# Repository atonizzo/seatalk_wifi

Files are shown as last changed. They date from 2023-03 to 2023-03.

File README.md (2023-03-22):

# <p align=center>SEATALK_WIFI</p>




---
### Table of contents
1. [Introduction](#introduction)
2. [Hardware](#hardware)
    1. [Schematic](#schematic)
        1. [Serial Bridge](#serial_bridge)
    2. [PCB Layout](#pcb_layout)
        1. [Front Side](#front_side)
        2. [Back Side](#back_side)
3. [Software](#software)
    1. [Configuration via Web Page](#web_page)
        1. [Programming Over the Air](#ota_programming)
        2. [Configuration for Wind Instrument](#wind_instrument)
    2. [Serial Logger](#serial_logger)
    3. [Telnet Logger](#telnet_logger)
    4. [NMEA Server](#nmea_server)
        1. [NMEA Talker](#nmea_talker)
    5. [Software Debug Port](#debug_port)
    6. [Integration with SignalK](#signalk)
    7. [Wind Gauges](#wind_gauges)
4. [Further Development](#further_development)
5. [Holder for ST40 devices](#st40_holder)
5. [Contact](#contact)
---

#  Introduction
The hardware and the included software of this project create a
bridge between a Raymarine SeaTalk1 instrument and NMEA. The NMEA
sentences generated are sent via a WiFi connection to a remote
client. This connection can be directly used with chart plotters such as
[OpenCPN](https://opencpn.org/).

The advantages of this solution are:

- Allows older instrumentation using SeaTalk1 to be connected to newer
chartplotters receiving NMEA sentences via WiFI
- The WiFi link allows the instrumentation to be installed in
out-of-the-way location thus freeing space in the navigation area
- The board can be installed very close to the data source and does not
require laying out data cables to a chart plotter. All that is needed
is a 12 Volt connection to the battery

#  Hardware
The hardware is a simple board with pads designed to connect to to a 12V
source on one side (typically a switched and fused boat battery) and to
a Seatalk connector on the other (see [PCB layout pictures](#pcb_layout))
board supplies 12V to power the target instrument so that the only
connection needed for the system to work is a single 12V feed from the boat
electrical panel.

The hardware board is not fused. It is expected that a 0.1A fast acting fuse
be provided on the 12V supply line immediately before the circuit. The 12V feed
that powers the circuit should also be fused at the distribution panel
or go through an appropriately sized resettable circuit breaker.

##  Schematic
Seatalk_wifi Schematic

During the development of the circuit it was noticed that the Raymarine
instrument being used (an ST40 wind instrument) was very sensitive about
loading of the SeaTalk serial line. To isolate the SeaTalk data line from
the rest of the circuitry Q2 acts as a buffer.

Q2 also inverts the polarity of the signal. The polarity is once again inverted
by the receiver integrated into U3, which also provides voltage translation
down to 3.3V.

U1 implements a regulator rated to least 2A. An earlier version of this board
designed with a linear regulator showed that the regulator tended to overheat,
which prompted a redesign using a switching topology.

###   Serial Bridge
R12 allows the board to be used as a receive-only serial to WIFI bridge. In
order to use this feature, the changes to the schematic are:

| Remove | Install |
| :---:  | :---: |
| Q1, Q2, R9 | R12 |

Now the center pad can be connected to the TX pin of the RS232 port of a
NMEA device and the serial stream of NMEA sentences can be sent out to
WIFI.

##  PCB Layout

The board has been designed using KiCad and the fabrication files are provided
in the ```fab``` directory.

Board dimensions are 31 mm x 22 mm.

###  Front Side
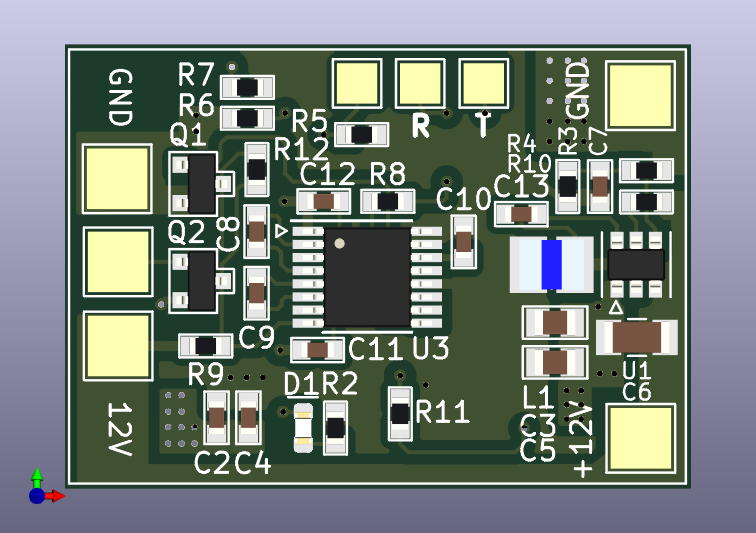
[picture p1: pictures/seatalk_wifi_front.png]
PCB Front Side


On the right side of the board the pads, from top to bottom, are:

- GND
- 12V (unfused, use a 500mA inline fuse)

These pads are connected to the boat battery. A better installation
would require powering this board from the same switched connection
that powers the navigation station.

On the left side of the board the pads are meant to be connected to a
Raymarine SeaTalk instrument. A SeaTalk1 cable has 3 wires that are
color coded and the typical color of the insulating jacket is shown
in the list. From top to bottom:

| Function | Jacket Color |
| :---: | :---: |
| GND | black or bare wire |
| SeaTalk | yellow |
| +12V |  red |

On the top side of the board the pads, from left to right, are:

- Serial Logger (unmarked on the PCB) This pin is connected to the TX pin
of serial port 2 of the ESP12 and -if enabled by the user- emits a
pretty print of all the commands handled by the hardware
(see [Serial Logger](#serial_logger))

- Programming cable RX line (marked with R in the layout). This is connected
to the RX pin of serial port 1 of the ESP12 and is primarily used to program
the device. Serial port 1 of the ESP12 device is used for both programming
the board as well as to receive the SeaTalk sentences from the instrument.
During development this means that this pin must be disconnected from the
programming cable before resetting the board to prevent interference between
the programmer hardware and the SeaTalk instrument. Failure to disconnect
this cable during regular use will prevent the SeaTalk sentences from
being received by the MCU

- Programming cable TX line (marked with T in the layout) is connected to the
TX pin of the ESP12 and is mainly used during programming. It can also be
used to output general purpose debug information but the terminal must be
programmed with the same serial parameters used by SeaTalk, which are
usually 4800 bauds, 8 bits, Even parity, 1 Stop bit.

Since the board power supply is 3.3V the typical programming is performed with a
USB to serial converter connected to pads R, T and GND. If no further software
development is expected the programming cable should be disconnected from the
board and the pads left unconnected.

###  Back Side
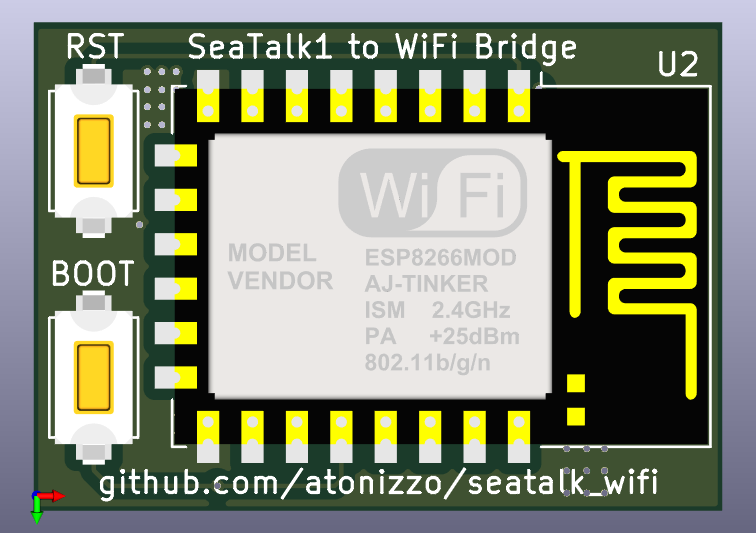
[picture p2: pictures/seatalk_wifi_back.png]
PCB Back Side


The two switches on the left side of the image are only used to program the
board when using the serial port. Once the initial firmware image is programmed
the OTA facility (see [Programming Over the Air](#ota_programming))
can then be used to reimage the flash memory thus not requiring neither the
serial port nor the toggling of the switches.

In order to program the board the RST switch (the top one in the picture)
should be pulsed **while the BOOT switch is kept pressed**. At this point
the board is ready for the programmer to write the new software.

#  Software
The software can be compiled using the Arduino GUI. The only library required
is Lennart Henning's ESPTelnet library which is used for the
both the Telnet server and the NMEA server.

##  Configuration via Web Page
The software runs a web server that serves a single web page used
to configure a few parameters of the bridge. Among other things the page allows
setting the output power for the WiFi transmitter, enabling or disabling
of the serial and telnet logging windows and the port
at which the NMEA server is listening. During the first start the software
creates a configuration space in EEPROM and stores a few default parameters.
The defaults have been chosen to aid in the debgging of the board during firts
installation and can be changed accordingly after full operation has been
achieved. The built in defaults are:

- Serial logger enabled
- Telnet logger enabled
- The default primary NMEA port is 3030
- The default NMEA talker is "LR"
- Activity LED enabled
- OTA programming enabled

An example of the web page is shown in the following picture.

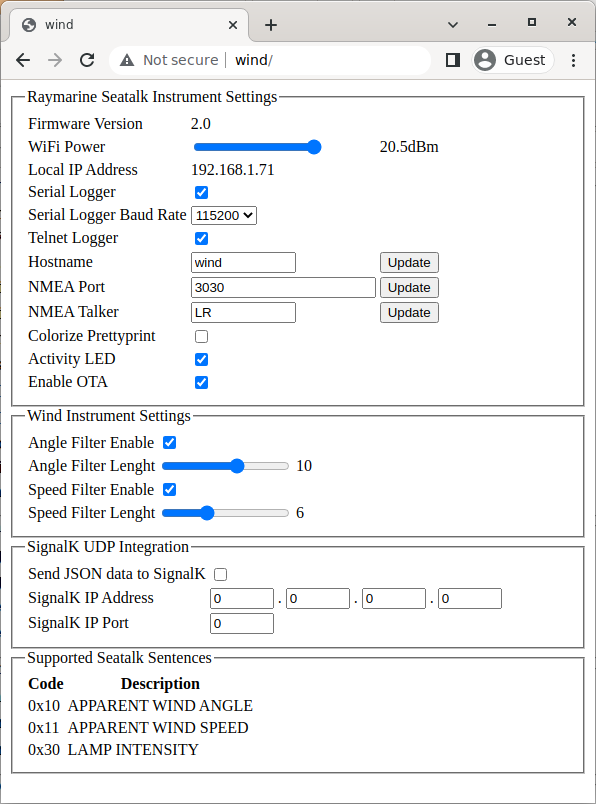
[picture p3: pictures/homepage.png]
Configuration Web Page


The default hostname for the instrument is "wind" and can be changed in the
software before programming (see [sw/seatalk_wifi.h](sw/seatalk_wifi.h))
or at a later point via the configuration web page.

The bottom of the web page also lists the SeaTalk sentences that are supported
by the firmware programmed on the brige.

###  Programming Over the Air
In order to upgrade the firmware it is convenient to use the "Over the Air"
(OTA) facility of the ESP8266. Once enabled by using the checkbox in the web
page and once the hardware has been reset, a new hostname is available, which
is the device hostname with the "_ota" string appended. For example, if the
device hostname is "wind", the OTA programmer will be available at the hostname
"wind_ota". Now the Arduino IDE or the appropriate Python script can be used
to flash a new image without the need to connect a USB to serial port converter.
Once the new firmware has been written the OTA programming can safely be disabled.

###  Configuration for Wind Instrument
In gusty wind conditions the wind angle -and to a lesser extent the speed- returned
by the wind instrument are subject to very quick jumps only to then return to
prevailing conditions. To filter out some of the noise introduced by these
jumps the angle and speed data can be independently processed by a simple
moving average filter. When these filters are enabled their lenght
can be configured using the web page in the fieldset specific to the wind
instrument.

##  Serial Logger
A timestamped pretty print of all the commands handled by the bridge is
printed out to the serial logger, connected to Serial1 (for wiring information
see [Front Side](#front_side)). This is not the actual NMEA
data but rather descriptive information of each Seatalk command in the
order that it was processed.

In the log -and assuming the coloring is enabled- the command byte is typically
printed in blue, the payload in the regular terminal color, the name of the
command in green and the arguments in terminal color.

Errors are also logged. In this case the byte that caused the error is shown
in red. If any error occurs the entire packet received up until that moment
is tossed and the software will start seeking another command to interpret.
There are 3 types of errors:

- Unrecognized commands, which are commands with the parity bit set but
that are not among those recognized by the software
- Parity violations, where a payload byte was received with the parity
bit set
- Framing violations, where one of the payload bytes was received that
was not consistent with the command being handled.

In the latter 2 cases the argument column provides information about
the offending byte.

##  Telnet Logger
The software runs a Telnet server that outputs a pretty print of all the
commands received, exactly the same information that can be output on the
serial port.

##  NMEA Server
The NMEA sentences are available at the port selected in the settings and
can be accessed directly via the communication configuration of
chartplotters such as [OpenCPN](https://opencpn.org/). The software
will send NMEA data to either NMEA ports as long as there is a connection.

There is a secondary NMEA server that serves the exact same content as
the primary and it can be connected at the primary port number plus one.

###  NMEA Talker
The NMEA talker can be selected through the web page configuration.
The default talker, written in EEPROM upon first boot, is "LR".

##  Software Debug Port
Since the Serial TX line of the programming cable (UART0_TXD in the schematic)
is not shared with SeaTalk it is used to send out debug information that is
useful during installation. To see the output of this port the terminal should
be configured with the same setting as SeaTalk (8 bit, Even parity, 1 Stop bit).
The information output shows the content of the configuration EEPROM as well
as the output from the connection to a WiFi network.

##  Integration with SignalK
Wind speed and direction can be optionally sent to SignalK via a UDP connection.
In the case of the wind instrument the following keys, in the form of serialized
JSON objects, are forwarded to SignalK:

`environment/wind/angleApparent`

`environment/wind/speedApparent`

The source for these keys is set by the firmware to be `Raymarine ST40 Wind`.

To read these keys SignalK must be set to receive a UDP connection from the
seatalk_wifi device. The IP address and port of the SignalK server can be
programmed into the seatlk_wifi device via the
[Configuration Web Page](#web_page).

##  Wind Gauges
In the case in which a connection to a display unit (e.g. OpenCPN or or
SignalK) is not available wind information can be read by means of a pair of
gauges available at the URL http://wind/gauges. This is useful in the case
where a cellphone or a pad is the only device available.

The gauges are updated every second with measured wind speed and direction. The
data is also accumulated and a temperature encoded histogram is created around
the edge of both dials. In this way it is possible to evaluate prevalent
wind condition for the past few minutes.

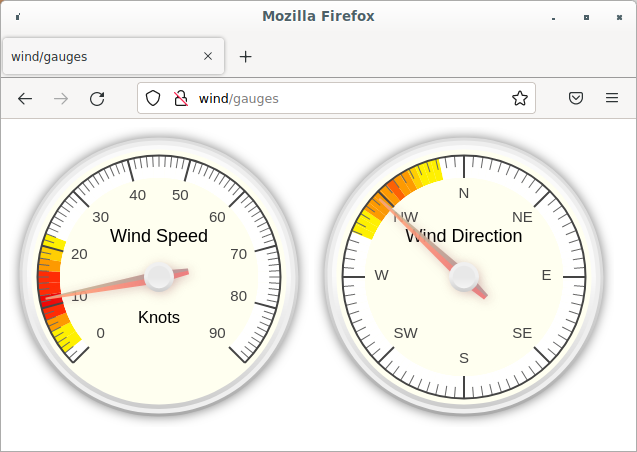
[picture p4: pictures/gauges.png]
Wind Gauges


The Javascript implementation for the gauges was written by Mykhailo Stadnyk
and it is under a MIT license. The GitHub repository can be found at
[Canvas Gauges](https://github.com/Mikhus/canvas-gauges).

#  Further Developmnent
The project can be improved in a number of ways.

## Handling Additional SeaTalk Sentences
The only instrument available during development was an ST40 wind instrument and
the messages that are emitted by that instrument are the only one currently
recognized by the software. The software processes the Seatalk sentences using
a state machine and it makes rather trivial job to add code that handles new
sentences.

## Adding the Ability to Transmit SeaTalk Sentences
The current release does not allow transmitting of Seatalk sentences because
there was no need for it in the only ST40 instrument used for development.

In receive mode, the parity bit is extracted using a technique that involves
checking for RX errors and then assuming that any such error is due to parity
violation (this is required by the way errors are handled in the serial library
of the ESP8266 device), but when sending data the parity bit has to be handled
as a 9th bit independent of the others which makes it impossible to use the
hardware serial port TX pin to do this. When configured to use serial parity
the ESP8266 core sets parity based on the bit pattern to send and does not allow
independently setting the value of the parity bit. For this reason the SeaTalk
TX line is connected to a GPIO in the expectation that a the TX signal can be
bit-banged out of it.

Since SeaTalk is a multiple access protocol the ability to transmit sentences
requires the need to detect possible interfence from other instruments trying
to talk over each other. Since the SeaTalk line is a single one, the
transmitted data is also received back by the bridge, which can compare it
with the data transmitted to detect collisions.

#  Holder for ST40 devices
With the NMEA data now sent via WiFI the ST40 device can optionally be
installed in a more secluded place, clearing up some space in the navigation
station. A 3D printed mount allows installing the bridge PCB behind the
instrument itself and holding the instrument in place with an M3x8
pinch cap screw.

The board is hidden underneath a lid, secured with 2 M2x6 screws, with
power supply wires entering from the bottom and wires to the instrument
coming out from the top.

Original FreeCAD file and STEP files are provided in the ```holder```
directory.

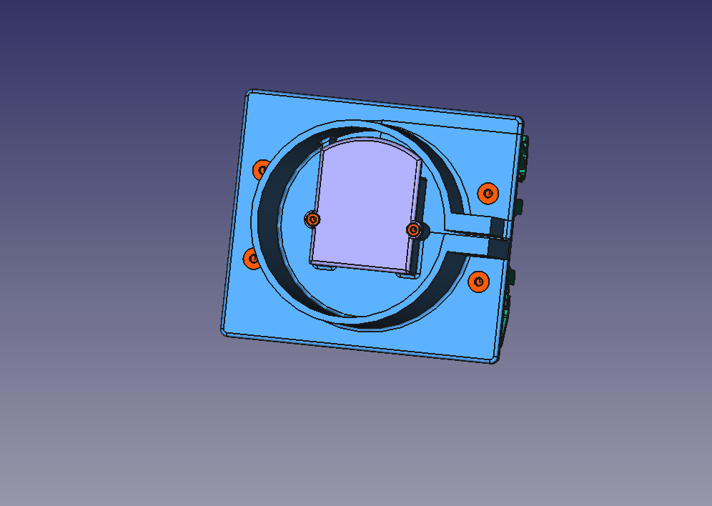
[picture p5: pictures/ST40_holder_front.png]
ST40 Holder Front


The mounting holes for the holder are 25 mm apart and are spaced to optionally
connect to a DIN rail clip using 3 mm flathead countersunk screws.

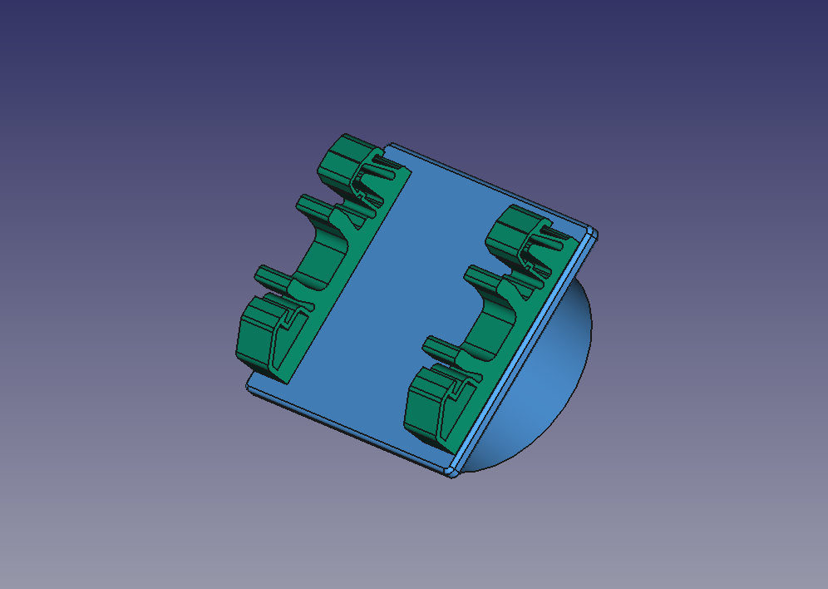
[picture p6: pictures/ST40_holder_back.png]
ST40 Holder Back


#  Contact
<atonizzo@gmail.com>

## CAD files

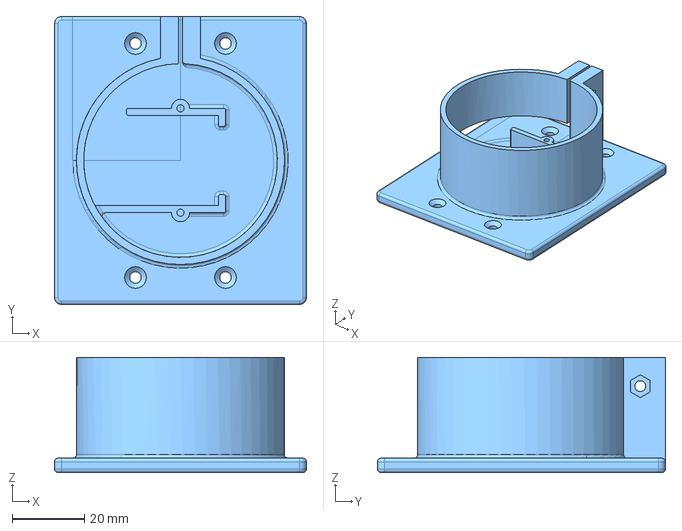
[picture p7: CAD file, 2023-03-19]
holder/ST40_holder.step
70.0 x 80.0 x 32.0 mm

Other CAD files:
holder/ST40_holder.FCStd

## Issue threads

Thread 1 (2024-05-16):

error compilation

yo3gts, 2024-05-16:
Hi, I try to compile with Arduino IDE 2.3.2 and I have some errors:

E:\Diverse\sw\sw.ino:62:38: warning: ISO C++ forbids converting a string constant to 'char*' [-Wwrite-strings]
   62 |     {SEATALK_APPARENT_WIND_ANGLE, 4, "APPARENT_WIND_ANGLE"},
      |                                      ^~~~~~~~~~~~~~~~~~~~~
E:\Diverse\sw\sw.ino:63:38: warning: ISO C++ forbids converting a string constant to 'char*' [-Wwrite-strings]
   63 |     {SEATALK_APPARENT_WIND_SPEED, 4, "APPARENT_WIND_SPEED"},
      |                                      ^~~~~~~~~~~~~~~~~~~~~
E:\Diverse\sw\sw.ino:64:38: warning: ISO C++ forbids converting a string constant to 'char*' [-Wwrite-strings]
   64 |     {SEATALK_LAMP_INTENSITY,      3, "LAMP_INTENSITY"},
      |                                      ^~~~~~~~~~~~~~~~
E:\Diverse\sw\sw.ino:66:38: warning: ISO C++ forbids converting a string constant to 'char*' [-Wwrite-strings]
   66 |     {SEATALK_UNSUPPORTED,         0, "UNSUPPORTED"},
      |                                      ^~~~~~~~~~~~~
E:\Diverse\sw\sw.ino: In function 'void print_framing_error(unsigned int)':
E:\Diverse\sw\sw.ino:432:42: warning: ISO C++ forbids converting a string constant to 'char*' [-Wwrite-strings]
  432 |     cursor_position = print_error_header("FRAMING ERROR");
      |                                          ^~~~~~~~~~~~~~~
E:\Diverse\sw\sw.ino: In function 'void print_parity_error()':
E:\Diverse\sw\sw.ino:441:24: warning: ISO C++ forbids converting a string constant to 'char*' [-Wwrite-strings]
  441 |     print_error_header("PARITY ERROR");
      |                        ^~~~~~~~~~~~~~
E:\Diverse\sw\sw.ino: In function 'void setup()':
E:\Diverse\sw\sw.ino:523:16: error: 'WIFI_SSID' was not declared in this scope; did you mean 'WIFI_STA'?
  523 |     WiFi.begin(WIFI_SSID, WIFI_PASS);
      |                ^~~~~~~~~
      |                WIFI_STA
E:\Diverse\sw\sw.ino:523:27: error: 'WIFI_PASS' was not declared in this scope; did you mean 'WIFI_AP'?
  523 |     WiFi.begin(WIFI_SSID, WIFI_PASS);
      |                           ^~~~~~~~~
      |                           WIFI_AP

exit status 1

Compilation error: 'WIFI_SSID' was not declared in this scope; did you mean 'WIFI_STA'?

I need to install more/other libraries?
Thank you

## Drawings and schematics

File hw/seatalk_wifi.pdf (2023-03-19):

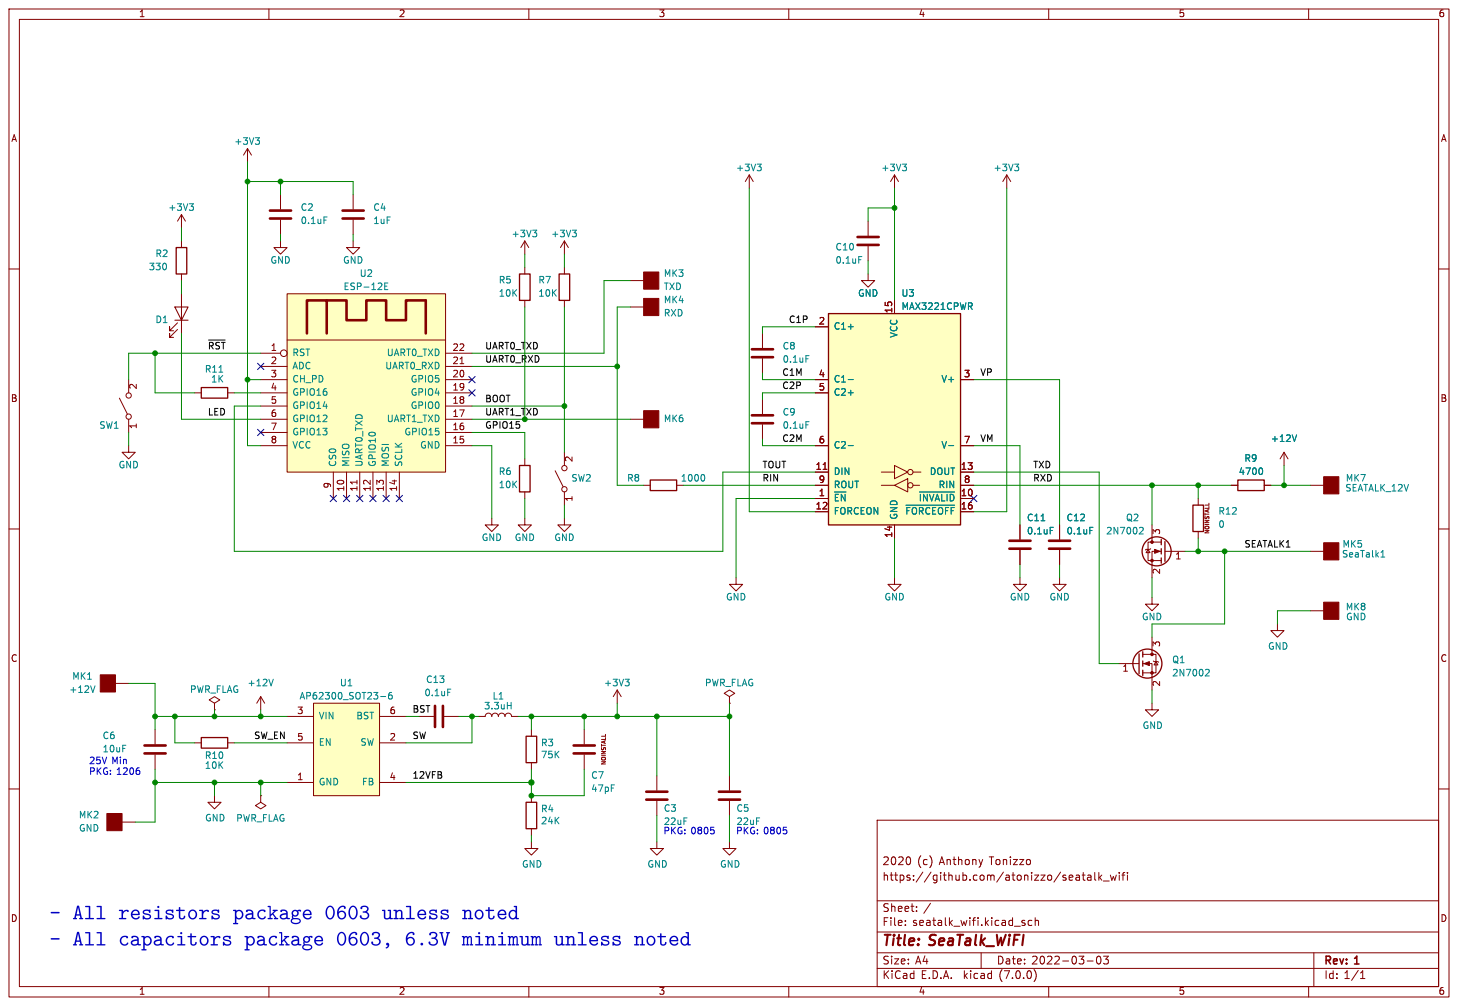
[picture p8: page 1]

- All capacitors package 0603, 6.3V minimum unless noted

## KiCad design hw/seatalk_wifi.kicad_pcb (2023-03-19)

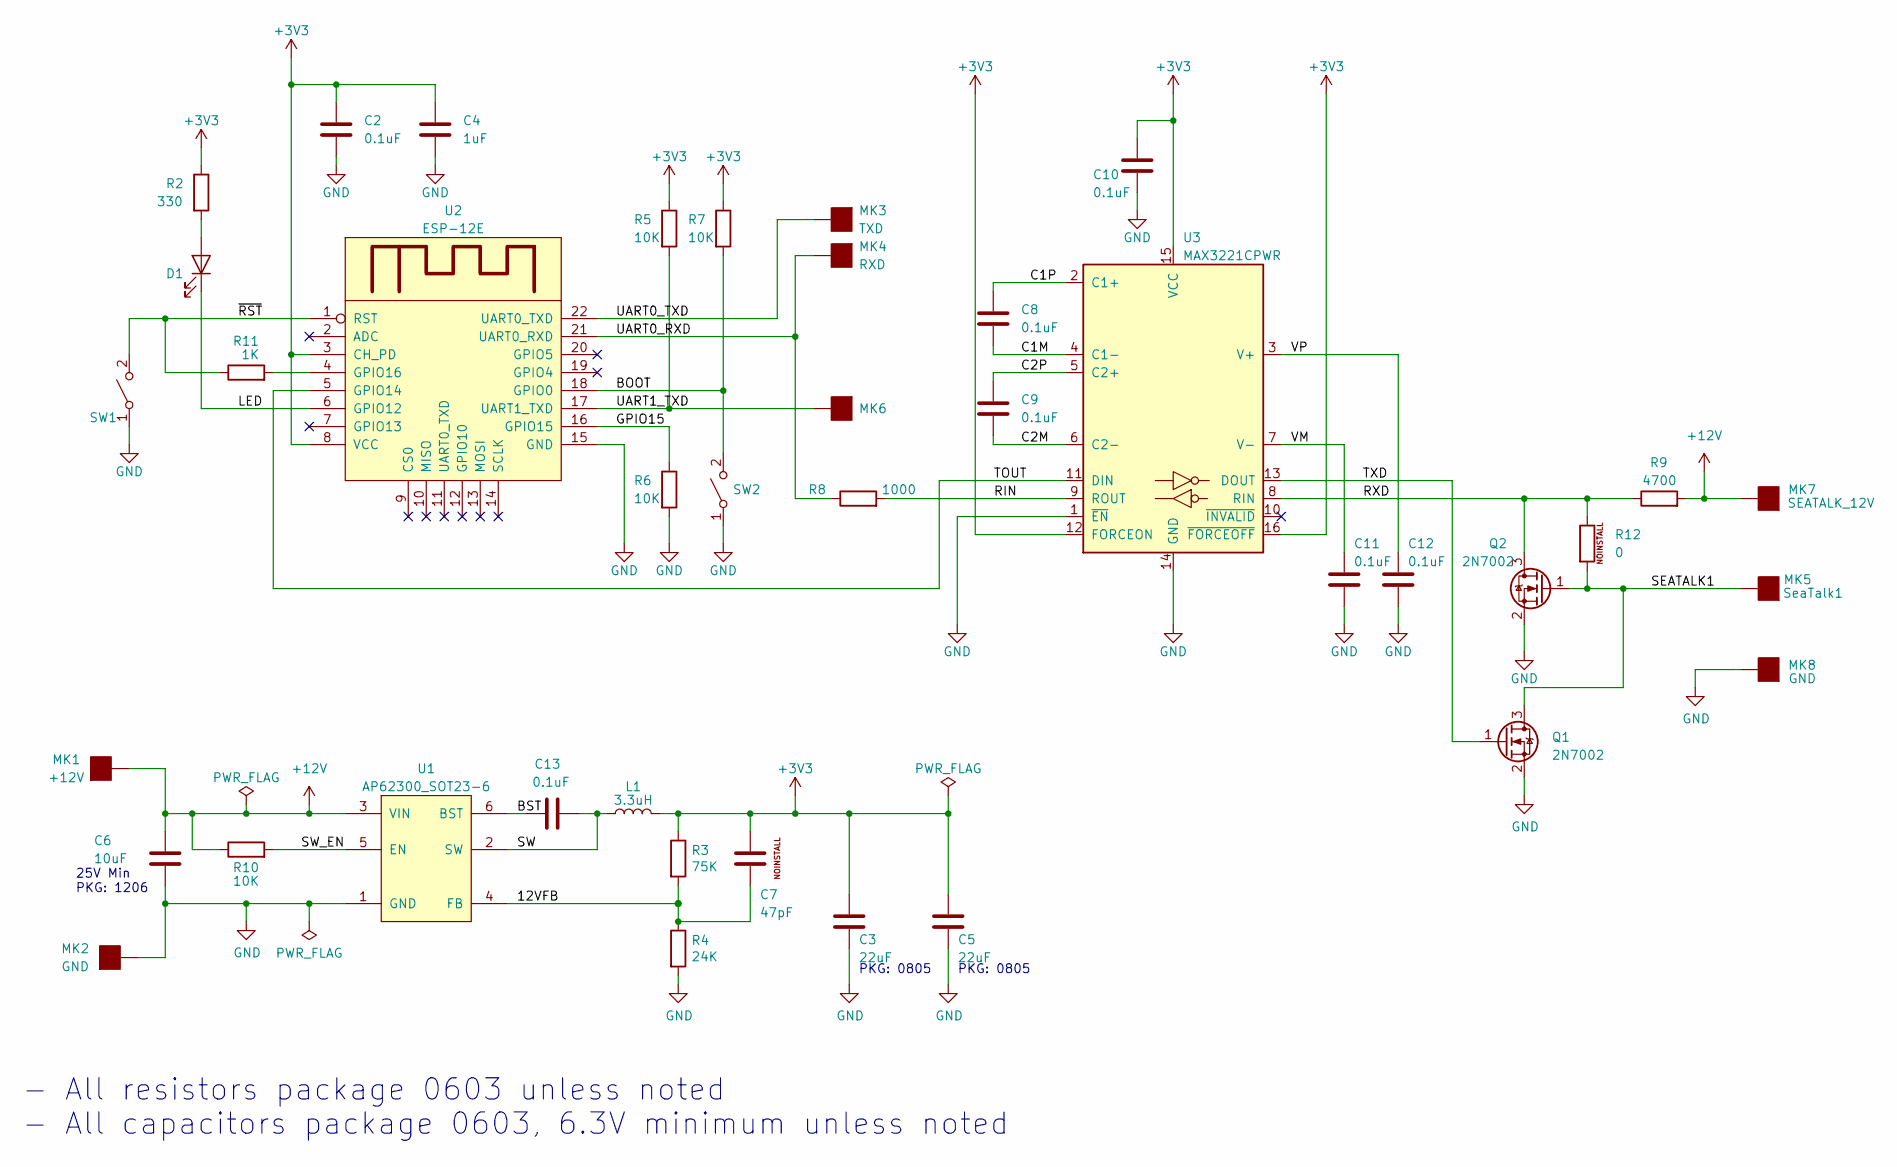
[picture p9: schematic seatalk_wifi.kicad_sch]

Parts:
C2, C8, C9, C10, C11, C12, C13: 0.1uF; C_0603_1608Metric; Voltage N/A; Tolerance N/A; MPN N/A; Digikey PN N/A
C3, C5: 22uF; C_0805_2012Metric; Voltage N/A; Tolerance N/A; MPN N/A; Digikey PN N/A
C4: 1uF; C_0603_1608Metric; Voltage N/A; Tolerance N/A; MPN N/A; Digikey PN N/A
C6: 10uF; C_1206_3216Metric; Voltage N/A; Tolerance N/A; MPN N/A; Digikey PN N/A
C7: 47pF; C_0603_1608Metric; Voltage N/A; Tolerance N/A; MPN N/A; Digikey PN N/A
D1: LED_A1K2; LED_0603_1608Metric; MPN N/A; Digikey PN N/A
L1: 3.3uH; INDC3225X120N; MPN N/A; Digikey PN N/A
MK1: +12V; TestPoint_Pad_3.0x3.0mm
MK2, MK8: GND; TestPoint_Pad_3.0x3.0mm
MK3: TXD; TestPoint_Pad_2.0x2.0mm
MK4: RXD; TestPoint_Pad_2.0x2.0mm
MK5: SeaTalk1; TestPoint_Pad_3.0x3.0mm
MK6: UART1; TestPoint_Pad_2.0x2.0mm
MK7: SEATALK_12V; TestPoint_Pad_3.0x3.0mm
Q1, Q2: 2N7002; SOT23-3; MPN 2N7002-G; Digikey PN TBA
R2: 330; R_0603_1608Metric; Tolerance N/A; MPN N/A; Digikey PN N/A
R3: 75K; R_0603_1608Metric; Tolerance N/A; MPN N/A; Digikey PN N/A
R4: 24K; R_0603_1608Metric; Tolerance N/A; MPN N/A; Digikey PN N/A
R5, R6, R7, R10: 10K; R_0603_1608Metric; Tolerance N/A; MPN N/A; Digikey PN N/A
R8: 1000; R_0603_1608Metric; Tolerance N/A; MPN N/A; Digikey PN N/A
R9: 4700; R_0603_1608Metric; Tolerance N/A; MPN N/A; Digikey PN N/A
R11: 1K; R_0603_1608Metric; Tolerance N/A; MPN N/A; Digikey PN N/A
R12: 0; R_0603_1608Metric; Tolerance N/A; MPN N/A; Digikey PN N/A
SW1, SW2: SW_SPST; ADTSM31NV
U1: AP62300_SOT23-6; SOT23-6; MPN AP62300WU-7; Digikey PN 31-AP62200TWU-7TR-ND
U2: ESP-12E; MPN ESP-12E; Digikey PN N/A
U3: MAX3221CPWR; TSSOP-16_4.4x5mm_P0.65mm; MPN MAX3221CPW; Digikey PN 296-26143-5-ND

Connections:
+3V3: C2.1, C3.1, C4.1, C5.1, C7.1, C10.1, L1.1, R2.1, R3.1, R5.1, R7.1, U2.3 (CH_PD), U2.8 (VCC), U3.12 (FORCEON), U3.15 (VCC), U3.16 (~FORCEOFF)
+12V: C6.1, MK1.1, MK7.1, R9.2, R10.1, U1.3 (VIN)
/12VFB: C7.2, R3.2, R4.1, U1.4 (FB)
/BOOT: R7.2, SW2.2 (B), U2.18 (GPIO0)
/BST: C13.1, U1.6 (BST)
/C1M: C8.2, U3.4 (C1-)
/C1P: C8.1, U3.2 (C1+)
/C2M: C9.2, U3.6 (C2-)
/C2P: C9.1, U3.5 (C2+)
/GPIO15: R6.1, U2.16 (GPIO15)
/LED: D1.2 (K), U2.6 (GPIO12)
/RIN: R8.2, U3.9 (ROUT)
/RXD: Q2.3 (D), R9.1, R12.1, U3.8 (RIN)
/SEATALK1: MK5.1, Q1.3 (D), Q2.1 (G), R12.2
/SW: C13.2, L1.2, U1.2 (SW)
/SW_EN: R10.2, U1.5 (EN)
/TOUT: U2.5 (GPIO14), U3.11 (DIN)
/TXD: Q1.1 (G), U3.13 (DOUT)
/UART0_RXD: MK4.1, R8.1, U2.21 (UART0_RXD)
/UART0_TXD: MK3.1, U2.22 (UART0_TXD)
/UART1_TXD: MK6.1, R5.2, U2.17 (UART1_TXD)
/VM: C11.1, U3.7 (V-)
/VP: C12.1, U3.3 (V+)
/~RST: R11.1, SW1.2 (B), U2.1 (RST)
GND: C2.2, C3.2, C4.2, C5.2, C6.2, C10.2, C11.2, C12.2, MK2.1, MK8.1, Q1.2 (S), Q2.2 (S), R4.2, R6.2, SW1.1 (A), SW2.1 (A), U1.1 (GND), U2.15 (GND), U3.1 (~EN), U3.14 (GND)
unnamed: D1.1 (A), R2.2
unnamed: R11.2, U2.4 (GPIO16)

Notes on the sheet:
PKG: 0805
- All resistors package 0603 unless noted - All capacitors package 0603, 6.3V minimum unless noted
25V Min PKG: 1206

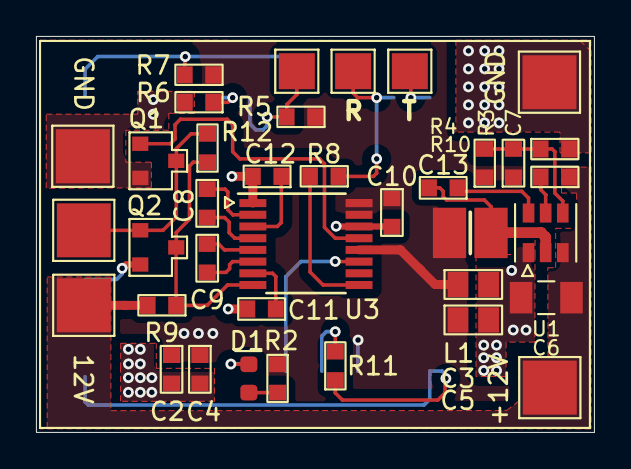
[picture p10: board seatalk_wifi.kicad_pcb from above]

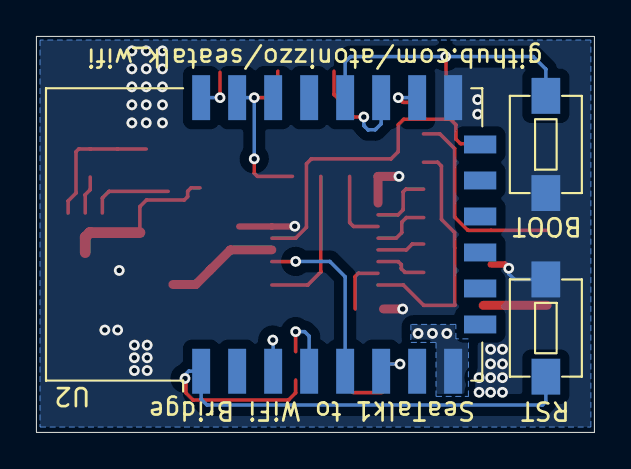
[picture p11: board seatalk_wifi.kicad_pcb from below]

Board: 2 copper layers, 31.0 x 22.0 mm, 40 parts (3 on the bottom side), 27 nets.

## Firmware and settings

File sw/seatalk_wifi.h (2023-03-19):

// Licensed under the Apache License, Version 2.0 (the "License");
// you may not use this file except in compliance with the License.
// You may obtain a copy of the License at
//
//     http://www.apache.org/licenses/LICENSE-2.0
//
// Unless required by applicable law or agreed to in writing, software
// distributed under the License is distributed on an "AS IS" BASIS,
// WITHOUT WARRANTIES OR CONDITIONS OF ANY KIND, either express or implied.
// See the License for the specific language governing permissions and
// limitations under the License.
//
// Author: Anthony Tonizzo - 2022

#ifndef __SEATALK_WIFI_H__
#define __SEATALK_WIFI_H__

typedef enum
{
    // The SM_STATE_SEEK_CMD looks for a byte from
    //  the input data stream that comes with the
    //  parity bit set.
    SM_STATE_SEEK_CMD           = 0,

    // The SM_STATE_PAYLOAD collects the payload
    //  bytes for the specific command just received
    //  during the SM_STATE_SEEK_CMD state. The number
    //  of bytes to receive is held in the
    //  seatalk_commands[] structure.
    SM_STATE_PAYLOAD            = 1,

    // The SM_STATE_SANITY_CHECK is meant to check if
    //  the stream of payload bytes that was received
    //  is correct.
    SM_STATE_SANITY_CHECK       = 2,

    // The SM_STATE_FORMAT state extract any relevant
    //  information from the payload bytes.
    SM_STATE_FORMAT             = 3,

    // The SM_STATE_SEND state creates the NMEA sentence
    //  and sends it out via the nmea_server.
    SM_STATE_SEND               = 4,

    // The SM_STATE_PRETTYPRINT state prints out a message
    //  to log the SeaTalk sentence that was just processed.
    SM_STATE_PRETTYPRINT        = 5,
} sm_state_t;

typedef enum
{
    SEATALK_APPARENT_WIND_ANGLE = 0x10,
    SEATALK_APPARENT_WIND_SPEED = 0x11,
    SEATALK_LAMP_INTENSITY      = 0x30,
    SEATALK_UNSUPPORTED         = 0xFFFF,
} seatalk_cmd_t;

struct __cmd
{
    seatalk_cmd_t cmd;  // Command byte.
    uint8_t bytes;      // Number of bytes other than the
                        //  command byte.
    const char *cmd_name;     // Command name for pretty print.
};

typedef enum
{
    TEXT_ATTRIB_NORMAL     = 00,
    TEXT_ATTRIB_FG_BLACK   = 30,
    TEXT_ATTRIB_FG_RED     = 31,
    TEXT_ATTRIB_FG_GREEN   = 32,
    TEXT_ATTRIB_FG_YELLOW  = 33,
    TEXT_ATTRIB_FG_BLUE    = 34,
    TEXT_ATTRIB_FG_MAGENTA = 35,
    TEXT_ATTRIB_FG_CYAN    = 36,
    TEXT_ATTRIB_FG_WHITE   = 37,
    TEXT_ATTRIB_BG_BLACK   = 40,
    TEXT_ATTRIB_BG_RED     = 41,
    TEXT_ATTRIB_BG_GREEN   = 42,
    TEXT_ATTRIB_BG_YELLOW  = 43,
    TEXT_ATTRIB_BG_BLUE    = 44,
    TEXT_ATTRIB_BG_MAGENTA = 45,
    TEXT_ATTRIB_BG_CYAN    = 46,
    TEXT_ATTRIB_BG_WHITE   = 47
} text_attribute_t;

#define SEATALK_CMD_COLUMN          32
#define SEATALK_ARG_COLUMN          60

#define SEATALK_DATARATE            4800
#define LOGPORT_DATARATE            115200

#define NMEA_SERVER_DEFAULT_PORT    3030
#define NMEA_DEFAULT_TALKER         "LR"

struct __status
{
    volatile uint32_t serial_logger         : 1;
    volatile uint32_t telnet_logger         : 1;
    volatile uint32_t slogger_baudrate      : 3;
    volatile uint32_t colorize_prettyprint  : 1;
    volatile uint32_t activity_led          : 1;
    volatile uint32_t wifi_power            : 8;
    volatile uint32_t enable_ota            : 1;
    volatile uint32_t signalk_udp_enable    : 1;
             uint32_t                       : 15;
};
typedef struct __status status_t;

struct __wind_data
{
    volatile uint32_t filter_angle_enable  : 1;
    volatile uint32_t filter_speed_enable  : 1;
    volatile uint32_t angle_ma_length      : 8;
    volatile uint32_t speed_ma_length      : 8;
             uint32_t                      : 14;
};
typedef struct __wind_data wind_data_t;

struct __sensor_data
{
    volatile status_t status;
    volatile uint32_t nmea_port;
    volatile uint8_t hostname[32];
    volatile uint8_t nmea_talker[3];
    wind_data_t wind_data;
    volatile uint8_t signalk_udp_ip[4];
    volatile uint32_t signalk_udp_port;
    volatile uint8_t reserved[1];
    volatile uint32_t magic_number;
};
typedef struct __sensor_data sensor_data_t;
extern sensor_data_t sensor_data, sensor_data_mem;

#define FIRMWARE_VERSION            "2.0"
#define EEPROM_SIZE                 sizeof(sensor_data_t)
#define MAGIC_NUMBER                0xABBACAFE
#define DEFAULT_HOSTNAME            "wind"

#define WIND_ANGLE_FILTER_TAPS      16
extern unsigned int wind_angle_history[WIND_ANGLE_FILTER_TAPS];
extern unsigned int last_wind_angle;

#define WIND_SPEED_FILTER_TAPS      16
extern unsigned int wind_speed_history[WIND_SPEED_FILTER_TAPS];
extern unsigned int last_wind_speed;

#define ACTIVITY_LED                12

#define DEFAULT_SIGNALK_SOURCE      "Raymarine ST40 Wind"

extern const int baudrates[];
void print_attribute(text_attribute_t);
unsigned long float_to_str(char *, float, int);

extern const char homepage[];

#endif

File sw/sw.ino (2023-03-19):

// Licensed under the Apache License, Version 2.0 (the "License");
// you may not use this file except in compliance with the License.
// You may obtain a copy of the License at
//
//     http://www.apache.org/licenses/LICENSE-2.0
//
// Unless required by applicable law or agreed to in writing, software
// distributed under the License is distributed on an "AS IS" BASIS,
// WITHOUT WARRANTIES OR CONDITIONS OF ANY KIND, either express or implied.
// See the License for the specific language governing permissions and
// limitations under the License.
//
// Author: Anthony Tonizzo - 2022-2023

#include <ESP8266WiFi.h>
#include <ESP8266WebServer.h>
// This sketch uses Benoit Blanchon's ArduinoJson library.
// https://github.com/bblanchon/ArduinoJson
#include <ArduinoJson.h>
#include <ArduinoOTA.h>
#include <WiFiUdp.h>
#include <EEPROM.h>
// This sketch uses Lennart Hennigs' ESPTelnet library.
// https://github.com/LennartHennigs/ESPTelnet
#include "ESPTelnet.h"
#include "seatalk_wifi.h"
#include "eeprom_helpers.h"

sensor_data_t sensor_data, sensor_data_mem;

#include "wifi_credentials.h"   // Define WIFI_SSID and WIFI_PASS here.
#include "web_pages.h"

char cmd_payload[16];   // Holds the payload of the SeaTalk sentence.
char nmea_message[96];  // Maximum NMEA sentence length is 82 bytes.
int current_state = SM_STATE_SEEK_CMD;

unsigned int wind_angle_history[WIND_ANGLE_FILTER_TAPS];
unsigned int last_wind_angle;
unsigned int wind_angle_sum;

unsigned int wind_speed_history[WIND_SPEED_FILTER_TAPS];
unsigned int last_wind_speed;
unsigned int wind_speed_sum;

// Text buffer for the serial and/or telnet loggers.
char str_logger[256];
unsigned long ms_timer;

constexpr int baudrates[] =
{
    // These values must match those in the SELECT tag in the
    //  HTML code.
    9600, 19200, 38400, 57600, 115200
};

// Number of the entry in the command array for the sentence just
//  received.
unsigned int table_item;
unsigned int packet_bytes_received = 0;
unsigned int cursor_position;
float apparent_wind_angle = 0., apparent_wind_speed = 0;

static struct __cmd seatalk_commands[] =
{
    {SEATALK_APPARENT_WIND_ANGLE, 4, "APPARENT_WIND_ANGLE"},
    {SEATALK_APPARENT_WIND_SPEED, 4, "APPARENT_WIND_SPEED"},
    {SEATALK_LAMP_INTENSITY,      3, "LAMP_INTENSITY"},
    // Add new entries to this table above this line.
    {SEATALK_UNSUPPORTED,         0, "UNSUPPORTED"},
};

ESP8266WebServer http_server(80);
WiFiUDP udp;

// This is the server that pushes the NMEA 0183 sentances to
//  requesting clients.
ESPTelnet nmea_server_pri, nmea_server_sec;
bool nmea_server_pri_connected = false;
bool nmea_server_sec_connected = false;

ESPTelnet telnet_logger;
bool telnet_logger_connected = false;

const char* sk_key_wind_angle = "environment/wind/angleApparent";
const char* sk_key_wind_speed = "environment/wind/speedApparent";

static void telnet_logger_connect(String ip)
{
    telnet_logger_connected = true;
    telnet_logger.print("\r\nTimestamp  Raw Data");
    int cursor_position = strlen("Timestamp  Raw Data");
    while (cursor_position < SEATALK_CMD_COLUMN)
    {
        telnet_logger.print(" ");
        cursor_position += 1;
    }
    telnet_logger.print("Command");
    cursor_position = SEATALK_CMD_COLUMN + strlen("Command");
    while (cursor_position < SEATALK_ARG_COLUMN)
    {
        telnet_logger.print(" ");
        cursor_position += 1;
    }
    telnet_logger.println("Arguments\r\n"
                   "------------------------------------"
                   "------------------------------------");
}

static void telnet_logger_disconnect(String ip)
{
    telnet_logger_connected = false;
}

static void nmea_server_pri_connect(String ip)
{
    nmea_server_pri_connected = true;
}

static void nmea_server_pri_disconnect(String ip)
{
    nmea_server_pri_connected = false;
}

static void nmea_server_sec_connect(String ip)
{
    nmea_server_sec_connected = true;
}

static void nmea_server_sec_disconnect(String ip)
{
    nmea_server_sec_connected = false;
}

int append_blanks(char *p, unsigned int to, unsigned int from)
{
    if (from >= to)
        return 0;
    int added = to - from;
    while (from < to)
    {
        strcat(p, " ");
        from += 1;
    }
    return added;
}

unsigned long float_to_str(char *p, float num, int precision)
{
    unsigned long character_count = 0;
    if (num < 0)
    {
        sprintf(p + strlen(p), "-");
        character_count = 1;
        num = -num;
    }

    // Round the float number to the precision requested.
    precision = min(10, precision);
    num += 5. / pow(10, precision + 1);
    character_count += sprintf(p + strlen(p), "%d", (long)num);
    if (precision == 0)
        return character_count;
    num -= (long)num;

    strcat(p, ".");
    character_count += 1;
    while (precision > 0)
    {
        num *= 10;
        sprintf(p + strlen(p), "%d", (int)num);
        num -= (int)num;
        character_count += 1;
        precision -= 1;
    }
    return character_count;
}

int nmea_compute_checksum(char *buf)
{
    unsigned int chksum = 0, i = 0;
    while (buf[i] != 0)
    {
        switch(buf[i])
        {
            case '$':
                i += 1;
                break;
            case '*':
                return chksum;
                continue;
            default:
                chksum ^= buf[i];
                i += 1;
                break;
        }
    }

    // Should not be here.
    return chksum;
}

void append_text_attribute(char *p, text_attribute_t c)
{
    if (sensor_data.status.colorize_prettyprint == 1)
    {
        strcat(p, "\e[");
        sprintf(p + strlen(p), "%dm", c);
    }
}

void print_attribute(text_attribute_t c)
{
    if (sensor_data.status.colorize_prettyprint == 1)
        Serial.printf("\e[%dm", c);
}

// From Hacker's Delight.
bool calculate_parity(unsigned int a)
{
    int y = a ^ (a >> 1);
    y = y ^ (y >> 2);
    y = y ^ (y >> 4);
    return y & 1;
}

bool parity_bit(int c)
{
    int should_parity = calculate_parity(c);

    // In the ESP8266 Serial.hasRxError() returns 1 when at least one
    //  of 3 different errors are present: Framing, parity and FIFO
    //  timout. Without madifying the standard library it is not
    //  possible to isolate the parity bit and thus this code makes the
    //  somewhat educated assumption that when Serial.hasRxError()
    //  returns an error it will be a parity violation.
    int has_rx_error = Serial.hasRxError();
    return should_parity ^ has_rx_error;
}

void reset_wind_data(void)
{
    // Wind direction filter initializaton.
    memset(wind_angle_history,
           0,
           sizeof(wind_angle_history[WIND_ANGLE_FILTER_TAPS]));
    last_wind_angle = 0;
    wind_angle_sum = 0;

    // Wind speed filter initializaton.
    memset(wind_speed_history,
           0,
           sizeof(wind_speed_history[WIND_SPEED_FILTER_TAPS]));
    last_wind_speed = 0;
    wind_speed_sum = 0;
}

static void prettyprint_command(char *p, unsigned int cursor_position)
{
    p[0] = '\0';
    cursor_position = sprintf(p, "[%08d] ", millis());
    append_text_attribute(p, TEXT_ATTRIB_FG_BLUE);
    cursor_position += sprintf(p + strlen(p), "%02X ", cmd_payload[0]);
    append_text_attribute(p, TEXT_ATTRIB_NORMAL);

    for (int i = 1; i < packet_bytes_received; i++)
        cursor_position += sprintf(p + strlen(p),
                                   "%02X ",
                                   cmd_payload[i]);
    append_blanks(p, SEATALK_CMD_COLUMN, cursor_position);
    append_text_attribute(p, TEXT_ATTRIB_FG_GREEN);
    strcat(p, seatalk_commands[table_item].cmd_name);
    append_text_attribute(p, TEXT_ATTRIB_NORMAL);
    cursor_position = SEATALK_CMD_COLUMN +
          strlen(seatalk_commands[table_item].cmd_name);
    append_blanks(p, SEATALK_ARG_COLUMN, cursor_position);
}

static void print_slogger_banner(void)

{
    Serial1.print("\r\nTimestamp  Raw Data");
    cursor_position = strlen("Timestamp  Raw Data");
    while (cursor_position++ < SEATALK_CMD_COLUMN)
        Serial1.print(" ");
    Serial1.print("Command");
    cursor_position = SEATALK_CMD_COLUMN + strlen("Command");
    while (cursor_position++ < SEATALK_ARG_COLUMN)
        Serial1.print(" ");
    Serial1.print("Arguments\r\n"
                   "------------------------------------"
                   "------------------------------------\r\n");
}

void handler_homepage()
{
    http_server.send(200, "text/html", homepage);
}

void handler_gauges()
{
    http_server.send(200, "text/html", gauges);
}

void handler_push_settings(void)
{
    String value = http_server.arg("slogger");
    if ((sensor_data.status.serial_logger == 0) &&
                                    (value.toInt() == 1))
        print_slogger_banner();
    sensor_data.status.serial_logger = value.toInt();
    value = http_server.arg("tlogger");
    sensor_data.status.telnet_logger = value.toInt();
    value = http_server.arg("slogger_baud");
    sensor_data.status.slogger_baudrate = value.toInt();
    if (http_server.arg("nmea_port").toInt() < 65536)
        sensor_data.nmea_port = http_server.arg("nmea_port").toInt();
    sensor_data.hostname[0] = '\0';
    strncat((char *)sensor_data.hostname,
            http_server.arg("hostname").c_str(),
            31);
    sensor_data.status.colorize_prettyprint = http_server.arg("colorize").toInt();
    sensor_data.status.activity_led = http_server.arg("led").toInt();
    sensor_data.status.enable_ota = http_server.arg("ota").toInt();
    sensor_data.nmea_talker[0] = toupper(http_server.arg("nmea_talker").c_str()[0]);
    sensor_data.nmea_talker[1] = toupper(http_server.arg("nmea_talker").c_str()[1]);
    sensor_data.nmea_talker[3] = '\0';
    if (http_server.arg("wifi_power").toInt() != sensor_data.status.wifi_power)
    {
        sensor_data.status.wifi_power = http_server.arg("wifi_power").toInt();
        WiFi.setOutputPower(0.5 * sensor_data.status.wifi_power);
    }
    http_server.send(200, "text/plain", "\r\n");
    commit_eeprom();
}

void handler_push_wind_settings(void)
{
    String value = http_server.arg("filter_angle_enable");
    sensor_data.wind_data.filter_angle_enable = value.toInt();
    value = http_server.arg("filter_speed_enable");
    sensor_data.wind_data.filter_speed_enable = value.toInt();
    value = http_server.arg("angle_length");
    sensor_data.wind_data.angle_ma_length = value.toInt();
    value = http_server.arg("speed_length");
    sensor_data.wind_data.speed_ma_length = value.toInt();
    http_server.send(200, "text/plain", "\r\n");
    commit_eeprom();
    reset_wind_data();
}

void handler_push_signalk_settings(void)
{
    String value = http_server.arg("signalk_udp_enable");
    sensor_data.status.signalk_udp_enable = value.toInt();
    value = http_server.arg("signalk_udp_ip_0");
    sensor_data.signalk_udp_ip[0] = value.toInt();
    value = http_server.arg("signalk_udp_ip_1");
    sensor_data.signalk_udp_ip[1] = value.toInt();
    value = http_server.arg("signalk_udp_ip_2");
    sensor_data.signalk_udp_ip[2] = value.toInt();
    value = http_server.arg("signalk_udp_ip_3");
    sensor_data.signalk_udp_ip[3] = value.toInt();
    value = http_server.arg("signalk_udp_port");
    sensor_data.signalk_udp_port = value.toInt();
    http_server.send(200, "text/plain", "\r\n");
    commit_eeprom();
    reset_wind_data();
}

void handler_pull_settings(void)
{
    char s[256];
    sprintf(s,
            "ipaddr=%s&slogger=%d&tlogger=%d&"
            "slogger_baudrate=%d&nmea_port=%d&"
            "hostname=%s&colorize=%d&led=%d&"
            "nmea_talker=%s&wifi_power=%d&ota=%d&"
            "fw_version=%s",
            WiFi.localIP().toString().c_str(),
            sensor_data.status.serial_logger,
            sensor_data.status.telnet_logger,
            sensor_data.status.slogger_baudrate,
            sensor_data.nmea_port,
            sensor_data.hostname,
            sensor_data.status.colorize_prettyprint,
            sensor_data.status.activity_led,
            sensor_data.nmea_talker,
            sensor_data.status.wifi_power,
            sensor_data.status.enable_ota,
            FIRMWARE_VERSION);
    http_server.send(200, "text/plain", s);
}

void handler_pull_wind_settings(void)
{
    char s[256];
    sprintf(s,
            "filter_angle_enable=%d&filter_speed_enable=%d"
            "&filter_angle_max=%d&filter_speed_max=%d"
            "&filter_angle_len=%d&filter_speed_len=%d",
            sensor_data.wind_data.filter_angle_enable,
            sensor_data.wind_data.filter_speed_enable,
            WIND_ANGLE_FILTER_TAPS,
            WIND_SPEED_FILTER_TAPS,
            sensor_data.wind_data.angle_ma_length,
            sensor_data.wind_data.speed_ma_length);
    http_server.send(200, "text/plain", s);
}

void handler_pull_signalk_settings(void)
{
    char s[256];
    sprintf(s,
            "signalk_udp_enable=%d&signalk_udp_ip_0=%d"
            "&signalk_udp_ip_1=%d&signalk_udp_ip_2=%d"
            "&signalk_udp_ip_3=%d&signalk_udp_port=%d",
            sensor_data.status.signalk_udp_enable,
            sensor_data.signalk_udp_ip[0],
            sensor_data.signalk_udp_ip[1],
            sensor_data.signalk_udp_ip[2],
            sensor_data.signalk_udp_ip[3],
            sensor_data.signalk_udp_port);
    http_server.send(200, "text/plain", s);
}

void handler_pull_wind_data(void)
{
    char s[64];
    sprintf(s, "wind_speed=");
    float_to_str(s + strlen(s), apparent_wind_speed, 1);
    strcat(s, "&wind_angle=");
    float_to_str(s + strlen(s), apparent_wind_angle, 1);
    http_server.send(200, "text/plain", s);
}

void handler_page_not_found(void)
{
    http_server.send(404, "text/plain", "404: Not found");
}

void sendout_strlogger(void)
{
    strcat(str_logger, "\r\n");
    if (sensor_data.status.serial_logger == 1)
        Serial1.print(str_logger);

    if (sensor_data.status.telnet_logger == 1)
        if (telnet_logger_connected == true)
            telnet_logger.print(str_logger);
}
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
void loop()
{
    int parity;
    unsigned int payload_byte;
    unsigned int seatalk_cmd;
    WiFiClient cl;

    if (millis() > ms_timer)
        digitalWrite(16, HIGH);

    if (sensor_data.status.enable_ota == 1)
        ArduinoOTA.handle();

    nmea_server_pri.loop();
    nmea_server_sec.loop();
    if (sensor_data.status.telnet_logger == 1)
        telnet_logger.loop();
    http_server.handleClient();

    switch (current_state)
    {
    case SM_STATE_SEEK_CMD:
        if (Serial.available() == 0)
            break;
        seatalk_cmd = Serial.read();
        parity = parity_bit(seatalk_cmd);
        if (parity == 1)
        {
            // Make sure that the command received is one of those
            //  currently supported, which are held in the
            //  seatalk_commands[] array.
            table_item = 0;
            do
            {
                if (seatalk_commands[table_item].cmd == seatalk_cmd)
                {
                    current_state = SM_STATE_PAYLOAD;
                    break;
                }
                table_item += 1;
            }
            while (seatalk_commands[table_item].cmd !=
                                                SEATALK_UNSUPPORTED);
            if (seatalk_commands[table_item].cmd == SEATALK_UNSUPPORTED)
                current_state = SM_STATE_PRETTYPRINT;
            cmd_payload[0] = seatalk_cmd;
            packet_bytes_received = 1;
        }
        break;
    case SM_STATE_PAYLOAD:
        if (Serial.available() == 0)
            break;
        payload_byte = Serial.read();
        cmd_payload[packet_bytes_received] = payload_byte;
        packet_bytes_received += 1;
        parity = parity_bit(payload_byte);
        if (parity == 1)
        {
            // Payload bytes are never supposed to have the parity
            //  bit set. We'll toss the entire frame.
            print_parity_error();
            current_state = SM_STATE_SEEK_CMD;
        }
        else
        {
            // Perform due diligence on the data received.
            switch (seatalk_commands[table_item].cmd)
            {
            case SEATALK_APPARENT_WIND_ANGLE:
            case SEATALK_APPARENT_WIND_SPEED:
                // First payload byte must be 0x01.
                if (cmd_payload[1] != 0x01)
                {
                    print_framing_error(0x01);
                    current_state = SM_STATE_SEEK_CMD;
                }
                break;
            case SEATALK_LAMP_INTENSITY:
                if (cmd_payload[1] != 0x00)
                {
                    print_framing_error(0x00);
                    current_state = SM_STATE_SEEK_CMD;
                }
                break;
            default:
                current_state = SM_STATE_FORMAT;
                break;
            }
            if ((current_state == SM_STATE_PAYLOAD) &&
                            (packet_bytes_received ==
                                seatalk_commands[table_item].bytes))
                current_state = SM_STATE_FORMAT;
        }
        break;
    case SM_STATE_FORMAT:
        switch (seatalk_commands[table_item].cmd)
        {
        case SEATALK_APPARENT_WIND_ANGLE:
            if (sensor_data.wind_data.filter_angle_enable == 1)
                // The moving average for the speed is done with
                //  values that are 2 times the ones reported by the
                //  instrument. This is done to avoid rounding issues.
                apparent_wind_angle = 0.5 *
                       ma_wind_angle((cmd_payload[2] << 8) +
                                         cmd_payload[3]);
            else
                apparent_wind_angle = 0.5 * ((cmd_payload[2] << 8) +
                                                 cmd_payload[3]);
            current_state = SM_STATE_SEND;
            break;
        case SEATALK_APPARENT_WIND_SPEED:
            if (sensor_data.wind_data.filter_speed_enable == 1)
                // The moving average for the speed is done with
                //  values that are 10 times the ones reported by the
                //  instrument. This is done to avoid rounding issues.
                apparent_wind_speed = 0.1 *
                       ma_wind_speed((cmd_payload[2] & 0x7F) * 10 +
                                     (cmd_payload[3] & 0x0F));
            else
                apparent_wind_speed = 1.0 * (cmd_payload[2] & 0x7F) +
                                0.1 * (cmd_payload[3] & 0x0F);
            if ((cmd_payload[2] & 0x80) != 0)
                // Value for speed is in m/s. We'll convert to knots.
                apparent_wind_speed *= 1.944;
            current_state = SM_STATE_SEND;
            break;
        case SEATALK_LAMP_INTENSITY:
            current_state = SM_STATE_PRETTYPRINT;
            break;
        default:
            current_state = SM_STATE_SEEK_CMD;
            break;
        }
        break;
    case SM_STATE_SEND:
        switch (seatalk_commands[table_item].cmd)
        {
        case SEATALK_APPARENT_WIND_SPEED:
            if ((nmea_server_pri_connected == true) ||
                (nmea_server_sec_connected == true))
                send_nmea_data(apparent_wind_angle, apparent_wind_speed);
            if (sensor_data.status.signalk_udp_enable == true)
                send_sk_data(sk_key_wind_speed, apparent_wind_speed);
            break;
        case SEATALK_APPARENT_WIND_ANGLE:
            if ((nmea_server_pri_connected == true) ||
                (nmea_server_sec_connected == true))
                send_nmea_data(apparent_wind_angle, apparent_wind_speed);
            if (sensor_data.status.signalk_udp_enable == true)
                send_sk_data(sk_key_wind_angle, apparent_wind_angle);
            break;
        default:
            break;
        }
        current_state = SM_STATE_PRETTYPRINT;
        if (sensor_data.status.activity_led == 1)
        {
            digitalWrite(ACTIVITY_LED, LOW);
            ms_timer = millis() + 100;
        }
        break;
    case SM_STATE_PRETTYPRINT:
        if ((sensor_data.status.serial_logger == 1) ||
                (sensor_data.status.telnet_logger == 1))
        {
            switch (seatalk_commands[table_item].cmd)
            {
            case SEATALK_APPARENT_WIND_ANGLE:
                prettyprint_command(str_logger, cursor_position);
                append_text_attribute(str_logger, TEXT_ATTRIB_FG_BLUE);
                float_to_str(str_logger, apparent_wind_angle, 1);
                strcat(str_logger, " deg");
                append_text_attribute(str_logger, TEXT_ATTRIB_NORMAL);
                break;
            case SEATALK_APPARENT_WIND_SPEED:
                prettyprint_command(str_logger, cursor_position);
                append_text_attribute(str_logger, TEXT_ATTRIB_FG_BLUE);
                float_to_str(str_logger, apparent_wind_speed, 1);
                strcat(str_logger, " knots");
                append_text_attribute(str_logger, TEXT_ATTRIB_NORMAL);
                break;
            case SEATALK_LAMP_INTENSITY:
                prettyprint_command(str_logger, cursor_position);
                append_text_attribute(str_logger, TEXT_ATTRIB_FG_BLUE);
                sprintf(str_logger + strlen(str_logger),
                        "%d",
                        (cmd_payload[2] & 0x0C) >> 2);
                append_text_attribute(str_logger, TEXT_ATTRIB_NORMAL);
                break;
            default:
                // Unsupported SeaTalk sentence.
                print_error_header(seatalk_commands[table_item].cmd_name);
                break;
            }
        }

        sendout_strlogger();
        current_state = SM_STATE_SEEK_CMD;
        break;
    default:
        break;
    }
}

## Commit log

2022-08-07 Added HW and SW directoires with entire project files.
    [seatalk_wifi-B_Cu.gbr, seatalk_wifi-B_Fab.gbr, seatalk_wifi-B_Mask.gbr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]
2022-08-13 Corrected bug in the wind direction sentence and others - Corrected a bug the caused wrong values to be reported for wind direction - Corrected a pretty printing issue - Better sanity check of the pa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
    [seatalk_wifi.h, seatalk_wifi.ino]
2022-08-15 Added activity LED and updated documentation.
2022-08-15 Added R12 which allows an RS232 to WiFi bridge function.
    [seatalk_wifi.kicad_pcb, seatalk_wifi.kicad_sch]
2022-08-15 Updated fab files to include R12.
    [seatalk_wifi-B_Cu.gbr, seatalk_wifi-B_Fab.gbr, seatalk_wifi-B_Mask.gbr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]
2022-08-16 Final changes to PCB layout and updated picture of schematic.
    [seatalk_wifi-B_Cu.gbr, seatalk_wifi-B_Mask.gbr, seatalk_wifi-B_Paste.gbr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]
2022-08-20 UART0_TXD now used for debug output. Added 3D files for holder.
    [ST40_holder.FCStd, ST40_holder.step, seatalk_wifi.kicad_pcb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]
2022-08-31 Wind moving averages and code cleanup - Added moving averages for wind angle and speed - Cleaned up web page code - Sped up EEPROM update - Corrected the prettyprint of parity, framing and unrecogniz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
    [seatalk_wifi.kicad_sch]
2022-09-07 Added WiFi power settings.
2022-09-07 Schematic chenged to reflect the voltage of input caps.
    [seatalk_wifi.kicad_pcb, seatalk_wifi.kicad_sch]
2022-10-19 New holder design.
    [ST40_holder.FCStd, ST40_holder.step, ST40_lid.FCStd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]
2023-03-19 Improvements to web page. SignalK integration. New holder design.
    [ST40_holder.FCStd, ST40_holder.step, ST40_lid.FCStd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]
2023-03-19 New PDF schematic file. Updated SVG schematic.
